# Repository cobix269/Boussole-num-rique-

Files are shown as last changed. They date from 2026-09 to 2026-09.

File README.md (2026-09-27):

# NORHALO

NORHALO est un projet de boussole numérique réalisé à l’aide d’un PCB qui permet à son utilisateur de retrouver le nord magnétique même dans le noir. Un écran lumineux affiche une flèche qui indique le nord grâce à un magnétomètre, des LEDs s’allument en fonction de la direction dans laquelle pointe la flèche.

**Figure 1 & 2 : visualisation 3D du PCB **  :    
  

  

## À propos :

Le projet est réalisé sous KiCad et comprend actuellement la conception du schéma électronique ainsi que celle du circuit imprimé et le code a implémenté dans le microcontrôleur.

## Composantes principales

| Type de composant | Référence / Modèle |
| :--- | :--- |
| **Accéléromètre** | MPU-6050 |
| **Alimentation** | USB-C |
| **Ecran** | *Non spécifié* |
| **LEDs** | WS2812B |
| **Level shifter** | 74AHCT1G125 |
| **Magnétomètre** | MMC5883MA |
| **Microcontrôleur** | STM32G071KBTxN |
| **Régulateur 3,3V** | AP2112K-3.3 |

---

**Fonctionnement** :


Le MMC5883MA est utilisé comme capteur magnétique pour mesurer le champ magnétique terrestre.

Le MPU-6050 apporte les informations inertielles permettant de prendre en compte l'orientation et les mouvements de la carte par rapport au sol.

Les données des capteurs sont traitées par le STM32G071KBTxN, qui peut déterminer la représentation de la direction à afficher.

Le code permet de fusionner ces données pour calculer un cap précis (compensé en inclinaison), puis met à jour l'écran central et pilote les LEDs (WS2812B) afin d'indiquer l'orientation.

## Alimentation :

La carte est prévue pour être alimentée via USB-C.

L'alimentation est ensuite régulée par un AP2112K-3.3 afin de fournir le domaine d'alimentation aux circuits fonctionnant en 3,3 V comme le microcontrôleur.

Le 74AHCT1G125 est utilisé dans la chaîne de commande des LED afin d'assurer l'interface logique entre le microcontrôleur et les WS2812B.

Les résistances sont utilisées comme résistance de pull-up pour le bus I2C, pour la configuration USB-C et pour la chaîne de commande des LEDs

Les condensateurs sont utilisés pour assurer le découplage local des circuits intégrés, la stabilisation de l’alimentation et le filtrage des variations rapides de tension.

Pour le placement des composants il est important que les condensateurs de découplage soient placés au plus près des composants qu’ils doivent découpler afin de réduire la longueur des connexions.

## Structure du projet

```text
.
└── Code_boussole 	       # code du projet               
    ├── Projet1.kicad_sch      # Schéma principal
    ├── Projet1.kicad_pcb      # Circuit imprimé
    ├── LED20.kicad_sch        # Schéma de l'affichage LED
    └── README.md              # Documentation du projet
```
Améliorations futures :

Passer sur batterie (LiPo / Li-Ion) : Ajoute un régulateur de charge USB et un circuit de basculement automatique entre l'USB et la batterie

Mesure de tension batterie : Ajoute un pont diviseur de tension connecté à une entrée ADC du STM32 pour afficher le pourcentage de batterie restant sur l'écran rond

Fusible réarmable : Ajoute une protection contre les surintensités juste après VBUS.

Visualisation du projet généré par IA : 



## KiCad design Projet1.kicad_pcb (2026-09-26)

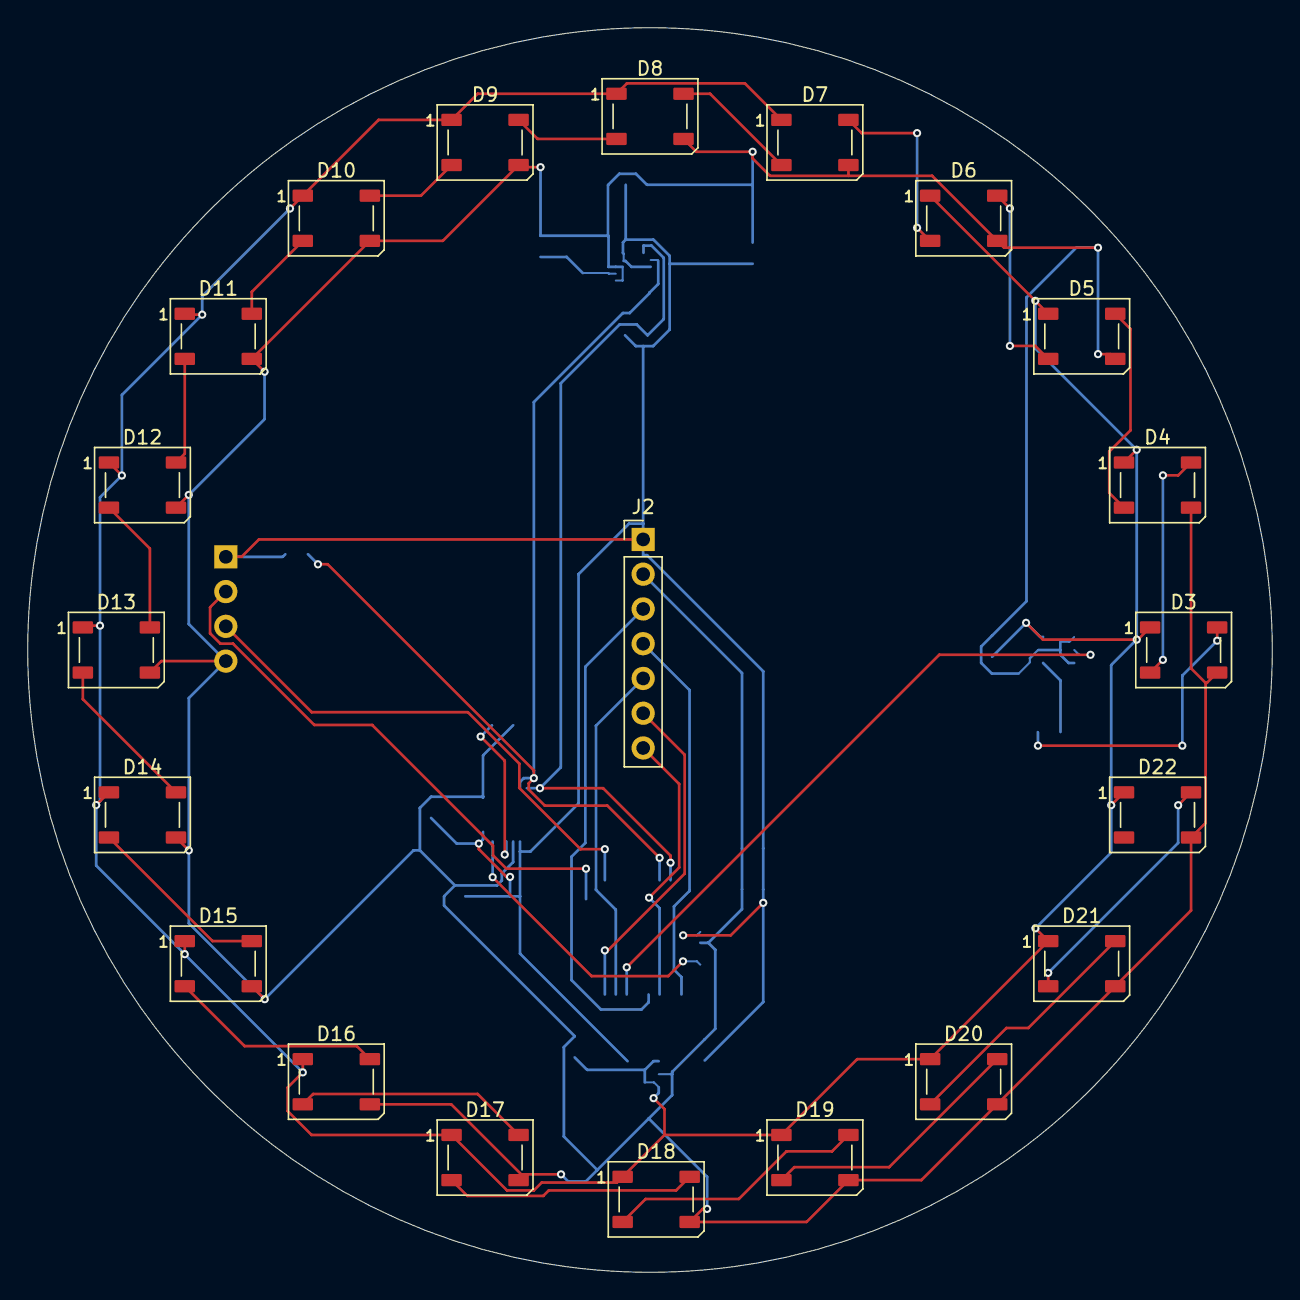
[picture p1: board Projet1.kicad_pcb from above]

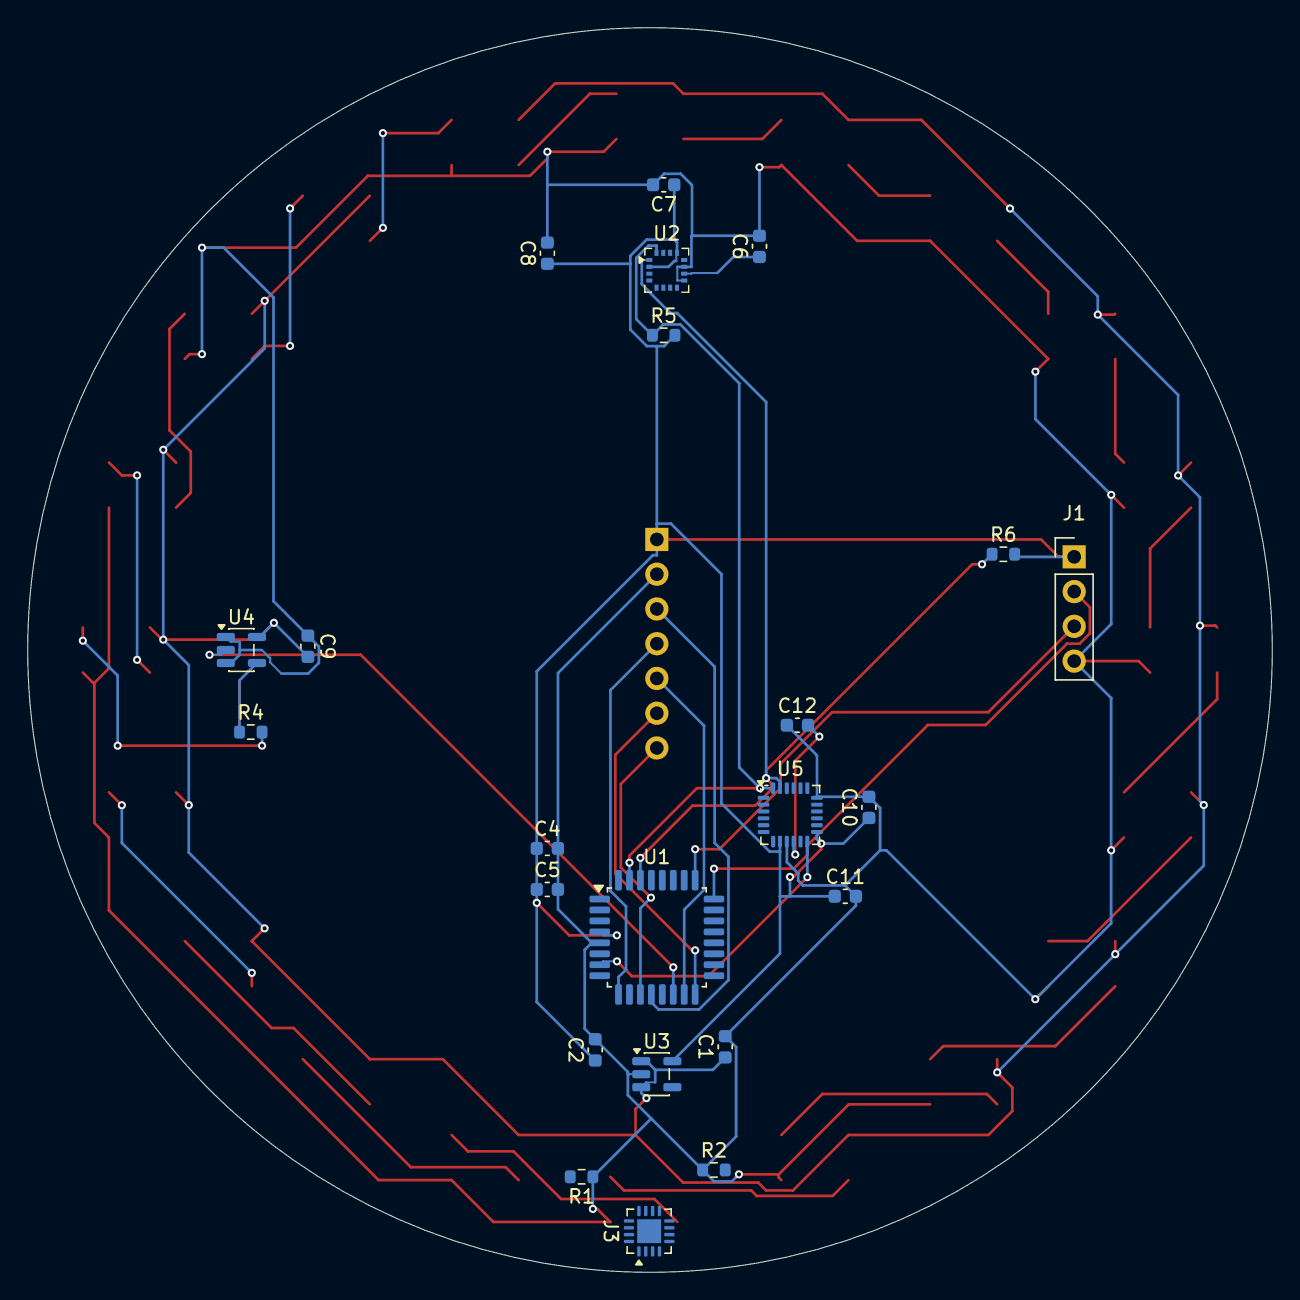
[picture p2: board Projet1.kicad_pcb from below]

Board: 2 copper layers, 91.0 x 91.0 mm, 44 parts (23 on the bottom side), 37 nets.

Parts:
C1, C2, C7: 1 µF; C_0603_1608Metric
C4, C8, C10: 100 nF; C_0603_1608Metric
C5: 4.7 µF; C_0603_1608Metric
C6: 10 µF; C_0603_1608Metric
C9: 100nF; C_0603_1608Metric
C11: 10; C_0603_1608Metric
C12: 10 nF; C_0603_1608Metric
D3, D4, D5, D6, D7, D8, D9, D10, D11, D12, D13, D14, D15, D16, D17, D18, D19, D20, D21, D22: WS2812B; LED_WS2812B_PLCC4_5.0x5.0mm_P3.2mm
J1: Conn_01x04; PinHeader_1x04_P2.54mm_Vertical
J2: Conn_01x07; PinHeader_1x07_P2.54mm_Vertical
J3: USB_C_Receptacle_PowerOnly_6P; WQFN-16-1EP_3x3mm_P0.5mm_EP1.75x1.75mm
R1, R2: 5.1 k; R_0603_1608Metric
R4: 330; R_0603_1608Metric
R5, R6: 2.7k; R_0603_1608Metric
U1: STM32G071KBTxN; LQFP-32_7x7mm_P0.8mm
U2: MMC5883MA; LGA-16_3x3mm_P0.5mm
U3: AP2112K-3.3; SOT-23-5
U4: 74AHCT1G125; SOT-23-5
U5: MPU-6050; InvenSense_QFN-24_4x4mm_P0.5mm

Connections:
+3.3V: C2.1, C4.1, C5.1, C7.1, C8.1, C10.1, C11.1, J1.1, J2.1, R5.2, R6.2, U1.4 (VDD), U2.2 (VDD), U2.13 (VDDIO), U3.5 (VOUT), U5.8 (VLOGIC), U5.13 (VDD)
+5V: C1.1, C9.2, D3.1 (VDD), D4.1 (VDD), D5.1 (VDD), D6.1 (VDD), D7.1 (VDD), D8.1 (VDD), D9.1 (VDD), D10.1 (VDD), D11.1 (VDD), D12.1 (VDD), D13.1 (VDD), D14.1 (VDD), D15.1 (VDD), D16.1 (VDD), D17.1 (VDD), D18.1 (VDD), D19.1 (VDD), D20.1 (VDD), D21.1 (VDD), D22.1 (VDD), U3.1 (VIN), U3.3 (EN), U4.5 (VCC)
/20 LEDS/LED_DATA_5V: R4.1, U4.4
ACC: U1.7 (PA0), U5.12 (INT)
GND: C1.2, C2.2, C4.2, C5.2, C6.2, C7.2, C8.2, C9.1, C10.2, C11.2, C12.1, D3.3 (VSS), D4.3 (VSS), D5.3 (VSS), D6.3 (VSS), D7.3 (VSS), D8.3 (VSS), D9.3 (VSS), D10.3 (VSS), D11.3 (VSS), D12.3 (VSS), D13.3 (VSS), D14.3 (VSS), D15.3 (VSS), D16.3 (VSS), D17.3 (VSS), D18.3 (VSS), D19.3 (VSS), D20.3 (VSS), D21.3 (VSS), D22.3 (VSS), J1.4, J2.2, R1.1, R2.1, U1.5 (VSS), U2.9 (GND), U2.11 (GND), U3.2 (GND), U4.1, U4.3 (GND), U5.9 (AD0), U5.18 (GND)
I2C_SCL: R6.1, U1.30 (PB6), U2.1 (SCL), U5.23 (SCL)
I2C_SDA: R5.1, U1.31 (PB7), U2.16 (SDA), U5.24 (SDA)
LCD_CS: J2.7, U1.11 (PA4)
LCD_DC: J2.5, U1.15 (PB0)
LCD_MOSI: J2.4, U1.9 (PA2)
LCD_RST: J2.6, U1.16 (PB1)
LCD_SCK: J2.3, U1.12 (PA5)
LED_DATA: U1.14 (PA7), U4.2
unnamed: D3.4 (DIN), R4.2
unnamed: D3.2 (DOUT), D4.4 (DIN)
unnamed: D4.2 (DOUT), D5.4 (DIN)
unnamed: D5.2 (DOUT), D6.4 (DIN)
unnamed: D6.2 (DOUT), D7.4 (DIN)
unnamed: D7.2 (DOUT), D8.4 (DIN)
unnamed: D8.2 (DOUT), D9.4 (DIN)
unnamed: D9.2 (DOUT), D10.4 (DIN)
unnamed: D10.2 (DOUT), D11.4 (DIN)
unnamed: D11.2 (DOUT), D12.4 (DIN)
unnamed: D12.2 (DOUT), D13.4 (DIN)
unnamed: D13.2 (DOUT), D14.4 (DIN)
unnamed: D14.2 (DOUT), D15.4 (DIN)
unnamed: D15.2 (DOUT), D16.4 (DIN)
unnamed: D16.2 (DOUT), D17.4 (DIN)
unnamed: D17.2 (DOUT), D18.4 (DIN)
unnamed: D18.2 (DOUT), D19.4 (DIN)
unnamed: D19.2 (DOUT), D20.4 (DIN)
unnamed: D20.2 (DOUT), D21.4 (DIN)
unnamed: D21.2 (DOUT), D22.4 (DIN)
unnamed: C6.1, U2.10 (CAP)
unnamed: C12.2, U5.10 (REGOUT)
SWD_CLK: J1.3, U1.25 (PA14)
SWD_I0: J1.2, U1.24 (PA13)

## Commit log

2026-09-26 Add files via upload
    First prototype
    [LED20.kicad_sch, Projet1.kicad_pcb, Projet1.kicad_sch]
2026-09-27 Mise à jour du schéma
    [Projet1.kicad_sch]
